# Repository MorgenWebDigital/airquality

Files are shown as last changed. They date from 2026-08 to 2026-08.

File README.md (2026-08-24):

# AirQuality

A battery-powered indoor air quality monitor. Real CO₂ from a photoacoustic
sensor, VOC and NOx, temperature, humidity and ambient light, shown on a 2.13"
e-paper display and sent over Bluetooth LE.

Two layers, 45 × 95 mm, 76 electrical components, one 21700 lithium cell.

| front | back |
|---|---|
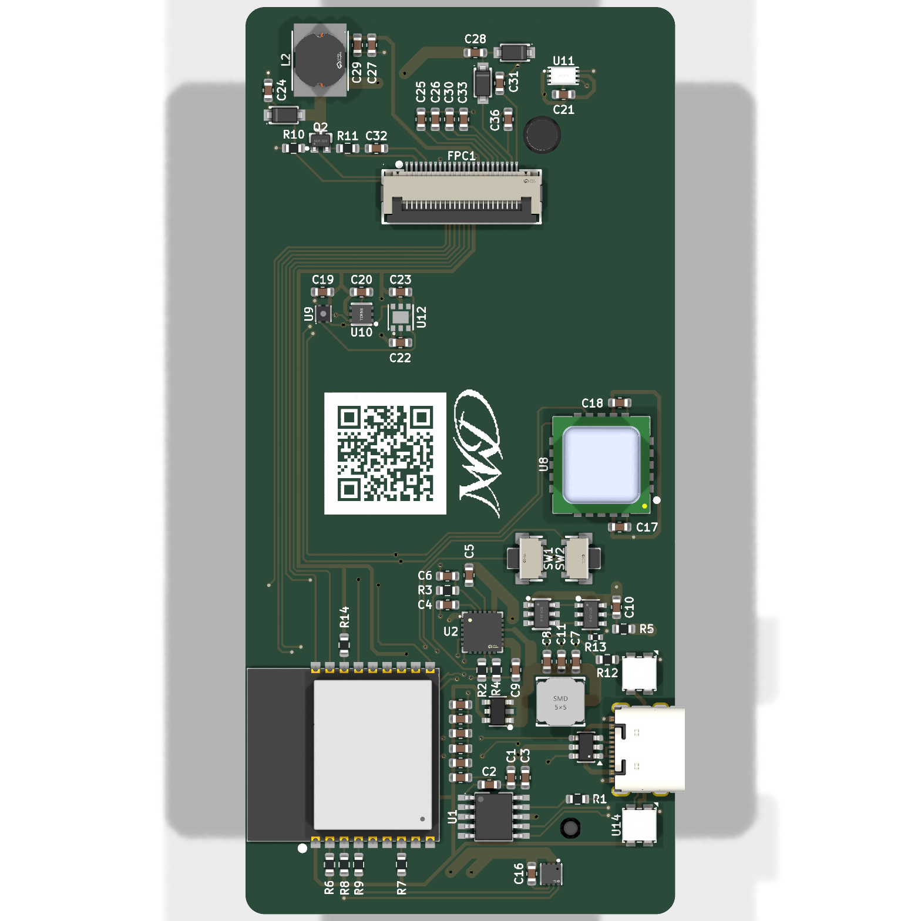
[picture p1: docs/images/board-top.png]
front
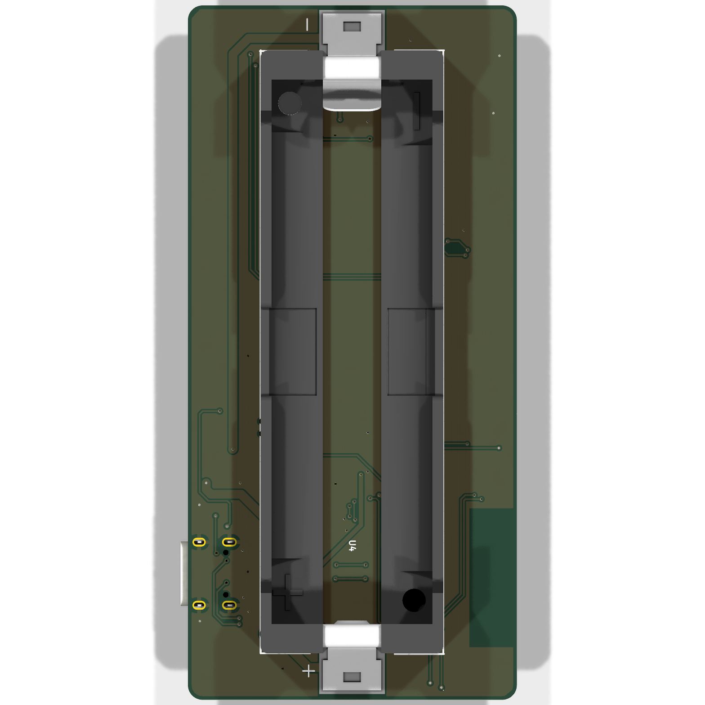
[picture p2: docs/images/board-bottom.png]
back
|  |  |

---

## 1. What it measures

| Sensor | Measures | Accuracy | I²C |
|---|---|---|---|
| **SCD40** | CO₂, photoacoustic, a real measurement rather than an estimate | ±(50 ppm + 5 % of reading) | `0x62` |
| **SGP41** | VOC and NOx index | index, not a concentration | `0x59` |
| **SHT41** | humidity and temperature | ±1.8 %RH, ±0.2 °C | `0x44` |
| **T117Z** | temperature, the precision channel | ±0.1 °C, 16 bit | `0x48` |
| **BH1750** | ambient light | 1 lx resolution, 1–65535 lx | `0x23` |
| **MAX17048** | state of charge of the cell | ±1 %, no shunt needed | `0x36` |
| **BQ25895** | charger status and control | - | `0x6A` |

Everything shares one I²C bus. The addresses do not collide.

The SCD40 is the only sensor that measures CO₂ directly. The SGP41 reports a
VOC and a NOx index derived from a heated metal-oxide cell. That reads as "the
air is getting stale", and is not comparable to a ppm figure.

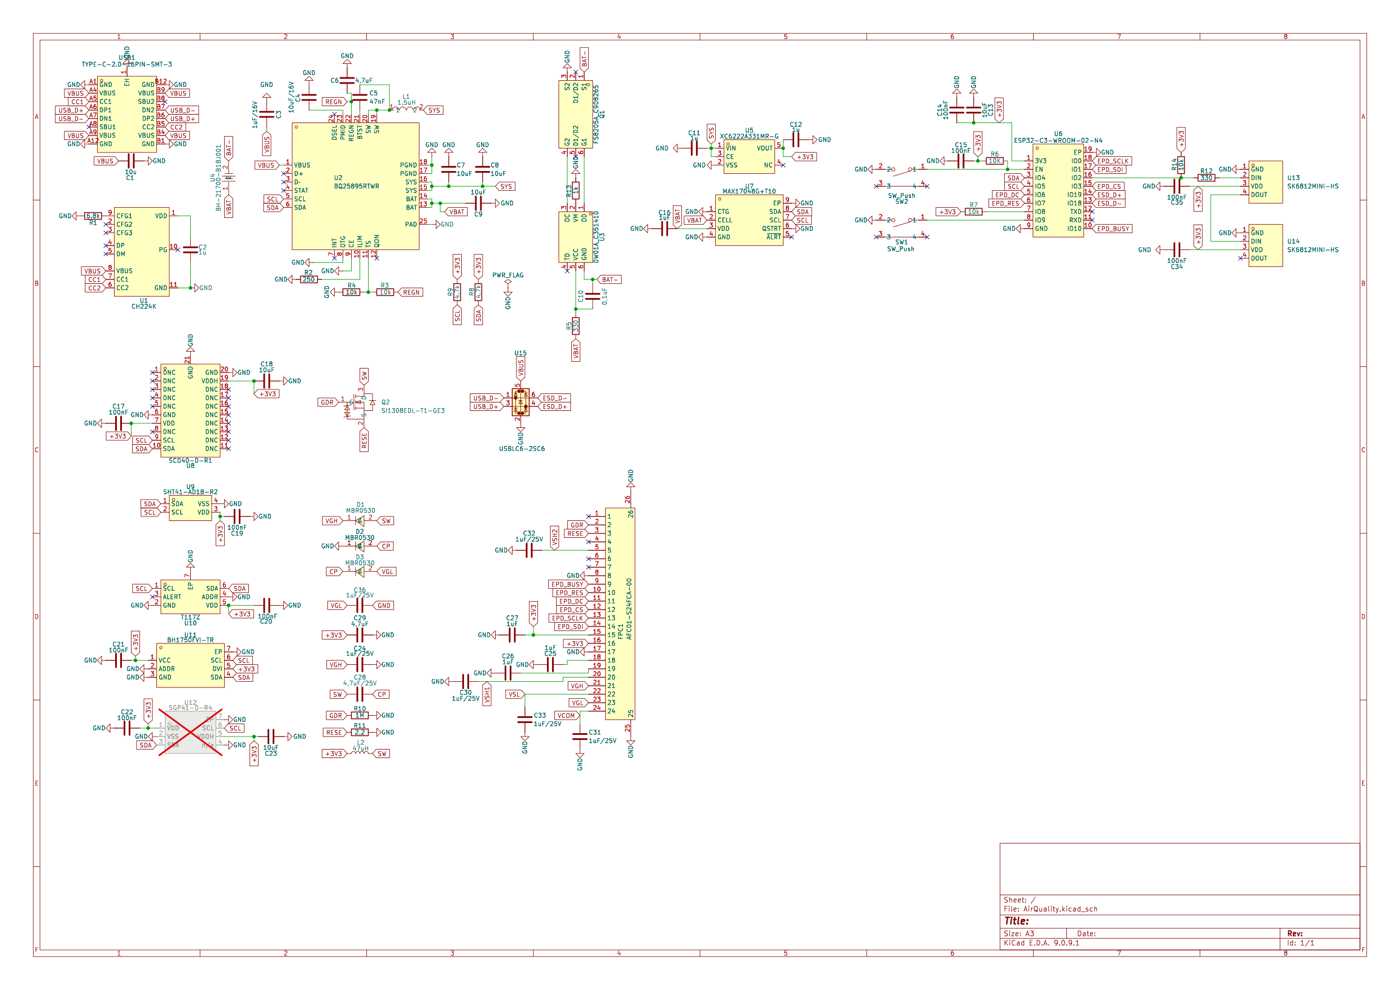
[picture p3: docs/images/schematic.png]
schematic


The full schematic as a PDF is in [`docs/schematic.pdf`](docs/schematic.pdf).

---

## 2. How the power works

```text
   USB-C ──▶ CH224K ──▶ VBUS ──▶ BQ25895 ──▶ SYS ──▶ XC6222 ──▶ 3.3 V
             requests            charger            LDO         MCU, sensors,
             9 V over PD                                        display
                                    │
                                    ▼
                                  21700 cell
                                    │
                              DW01A + FS8205A
                              cell protection
```

The **CH224K** negotiates 9 V over USB Power Delivery. At 9 V the charger draws
about half the current it would at 5 V for the same charging power. Less loss
in the cable, less heat. A 6.8 kΩ resistor on CFG1 selects the voltage; the
value comes straight from the table in the CH224K datasheet.

The **BQ25895** is a switching charger, not a linear one. It can deliver up to
5 A; the input current limit is set by a 250 Ω resistor to about 2.1 A. It also
provides the power path, so the device runs from USB while charging.

The cell is a **Molicel INR21700-P45B**, which ships unprotected. **DW01A** with
an **FS8205A** dual MOSFET adds over-charge, over-discharge and over-current
protection. A 1 kΩ resistor sits between the DW01A's VM pin and the pack
negative, as the datasheet's application circuit requires. Without it, plugging
in a charger while the protection has tripped puts the full charger voltage on
that pin with nothing to limit the current.

The **XC6222** drops SYS to 3.3 V. Its CE pin is tied to SYS: the regulator is
always on while the cell has charge. It cannot be switched off from the ESP32,
because the ESP32 hangs on that same rail and could never switch it back on.

---

## 3. The display

A 2.13" e-paper panel (GDEY0213B74, SSD1680 controller) on a 24-pin 0.5 mm FPC
connector. Bistable: it holds the image with no power at all, and only draws
current while updating.

The panel needs gate and source rails well beyond 3.3 V. They are generated on
the board, following the reference circuit in the panel's datasheet:

- a boost converter produces **VGH**: a 47 µH inductor and an SI1308 MOSFET,
  driven by the panel's own GDR output with a 2.2 Ω sense resistor on RESE
- a charge pump off the same switching node produces the negative **VGL**
- the other rails (VSH1, VSH2, VSL, VCOM) come from the panel's internal
  regulators and only need decoupling

All seven capacitors on these rails are rated **25 V**. That is not decoration:
VGH runs above 20 V, and a standard 1 µF 0603 from the shelf is often a 6.3 or
16 V part.

**BS1 is tied low**, which selects 4-wire SPI, matching the SDA/SCL/CS/DC/RES
wiring used here.

**Update budget.** The panel is rated for one million updates *or* five years,
whichever comes first. At one update per minute the update budget is gone in
under two years; at three minutes and longer, the five-year limit is reached
first. Redrawing no more often than every three minutes, and only when a value
actually changes, keeps the panel inside both limits.

---

## 4. Board details

| | |
|---|---|
| Size | 45 × 95 mm |
| Layers | 2, 35 µm copper |
| Ground | pour on the back, 3306 mm² |
| Minimum clearance | 0.2 mm |
| Minimum track | 0.2 mm |
| Vias | 0.6 mm pad, 0.3 mm drill |

**The ESP32 antenna** sits at the board edge with a keep-out on both copper
layers. Nothing is routed through it: no track, no via, no pour.

**ESD protection** on the USB data lines: a USBLC6-2SC6 sits 1.9 mm from the
connector pads, with the signal routed *through* the device rather than
branched off it, and a ground via right at its ground pad. Both matter more
than they look: an ESD pulse rises in under a nanosecond, and every millimetre
of track between the connector and the clamp adds roughly 35 V of overshoot
that the ESP32 then sees.

**U12 (SGP41) is marked do-not-populate.** The footprint and routing are there;
the part is left off in the current build. Fitting it later needs no board
change.

---

## 5. Building one

Everything needed is in this repository.

**Boards.** [`production/AirQuality-gerber.zip`](production/) goes straight to a
fab house. Two layers, 1.6 mm, 35 µm copper, any standard process. The zip holds
the Gerbers and the Excellon drill files.

**Parts.** [`production/AirQuality-bom.csv`](production/) lists every component
with its LCSC number where one exists.
[`production/AirQuality-positions.csv`](production/) is the pick-and-place file.

**Datasheets** for every active part are in [`datasheets/`](datasheets/), named
by LCSC part number.

**Opening the design.** KiCad 9. Open
[`hardware/AirQuality.kicad_pro`](hardware/). All symbols, footprints and 3D
models live in `hardware/libraries/` and are referenced relatively, so the
project opens from any location.

**Mechanical.** [`docs/AirQuality.step`](docs/) is the full board with all
components, for enclosure design.

---

## 6. Design notes

Longer notes on why things are the way they are:

- [`docs/design-notes.md`](docs/design-notes.md): component choices and the
  reasoning behind them
- [`docs/track-widths.md`](docs/track-widths.md): current, trace widths and
  the IPC-2221 arithmetic

---

## 7. Verification

The board passes with no electrical findings:

```text
   ERC                      0 errors, 0 warnings
   Unconnected pads         0
   Shorts                   0
   Clearance violations     0
   Schematic parity         0
```

Every integrated circuit has been checked pin by pin against its datasheet. Not
against memory or a symbol's label, but against the document in
[`datasheets/`](datasheets/).

Remaining DRC output is silkscreen only: reference designators over copper and
part outlines crossing the board edge at the connectors. Neither affects
manufacture.

---

## 8. License

[PolyForm Noncommercial 1.0.0](LICENSE). Any use is permitted except a
commercial one.

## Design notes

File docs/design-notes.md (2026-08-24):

# Design notes

Why the parts are what they are, and what was tried before them. Written from
the board as built, not from the plan. The two diverged along the way.

---

## 1. Sensors

**SCD40 for CO₂.** The only sensor here that measures CO₂ rather than guessing
at it. It works photoacoustically: infrared light is pulsed at CO₂ molecules in
a small chamber, they warm and expand, and a microphone hears the pressure
pulse. Accuracy ±(50 ppm + 5 % of reading).

Its datasheet is unusually specific about the supply: ripple below 30 mV
peak-to-peak, no large transient drops, and a low-dropout regulator preferred.
That is not politeness. The sensor draws 205 mA peaks during a measurement and
18 mA average, and a supply that sags under that peak gives wrong readings.
VDD and VDDH must sit at the same voltage and are tied together close to the
part.

**SGP41 for VOC and NOx.** A heated metal-oxide cell. It reports an *index*,
not a concentration. It reads as "the air is getting stale", and is not
comparable to ppm. It is the only part on the board that heats continuously
while measuring, at about 11 mW.

The plan originally called for an ENS160. It needs a 1.71–1.98 V core supply,
which would have meant a second regulator on a board that otherwise runs on one
rail. The SGP41 runs from 3.3 V and needed no extra hardware.

**SHT41 and T117Z for temperature.** Two sensors on purpose. The SHT41 gives
humidity plus a temperature good to ±0.2 °C. The T117Z is a
TMP117-register-compatible part from Mysentech that reaches ±0.1 °C for a
fraction of the TI original's price. It is the precision channel; the SHT41's
temperature is there mostly to compensate its own humidity reading.

The T117Z's ADD0 pin is tied to ground, which selects address `0x48`.

**BH1750 for light.** Its DVI pin is the I²C reference voltage, not a reset.
Tied to 3.3 V it sets the logic level. ADDR to ground gives `0x23`.

---

## 2. Power

**Why a PD trigger at all.** The CH224K negotiates 9 V over USB Power Delivery
instead of accepting the default 5 V. For the same charging power the input
current halves: less loss in the cable, less heat in the connector, less heat
in the charger. A 6.8 kΩ resistor on CFG1 selects 9 V; the value is the
datasheet's, not a guess. CFG2 and CFG3 must be left floating for the
single-resistor mode, and they are.

9 V is also comfortably inside the BQ25895's 3.9–14 V input range.

**Why a switching charger.** The plan started with an MCP73831, a linear
charger limited to 0.5 A. A 4500 mAh cell at 0.5 A takes nine hours, and the
regulator burns the difference between input and cell voltage as heat. The
BQ25895 switches instead, handles up to 5 A, and can be told what to do over
I²C. The input current limit is set by a 250 Ω resistor to about 2.1 A.

The TS pin has a fixed 10 k/10 k divider from REGN instead of a thermistor,
which puts it at 50 % of REGN, inside the window where the charger considers
the cell temperature normal and charges. Adding a real NTC later needs only the
two resistors swapped.

**Why cell protection is separate.** The Molicel P45B ships unprotected. The
DW01A watches the cell and switches an FS8205A dual MOSFET: over-charge above
4.25 V, over-discharge below 2.4 V, over-current, short circuit. It works
whether or not the charger is running or the microcontroller is awake.

The FS8205A's two drains are internally connected and brought out on pins 2 and
5; both are left unconnected, which is correct. The pair sits in series in the
cell's negative path with the sources at either end.

A 1 kΩ resistor sits between the DW01A's VM pin and the pack negative. The
datasheet's application circuit shows it and the reason is in the absolute
maximum ratings: VM tolerates VDD−24 V to VDD+0.3 V. With the protection
tripped and a charger connected, the full charger voltage lands on that pin,
and without the resistor nothing limits the current into it. Leaving it out is
a known way to kill a DW01A.

**Why the regulator can't be switched off.** The XC6222's CE pin is active
high and tied to SYS, so the regulator runs whenever the cell has charge. It is
tempting to put that pin on a GPIO for a hard power-down, but the ESP32 runs
from the very rail it would be switching, and could never switch it back on.

---

## 3. The e-paper supply

The panel's own controller runs the boost converter: it drives the gate of an
external MOSFET from its GDR pin and senses the current on RESE. All the board
provides is the power stage: a 47 µH inductor, an SI1308 MOSFET, a 2.2 Ω sense
resistor and three Schottky diodes.

Two things about this circuit are easy to get wrong, and both were:

**Diode polarity.** For the boost, the anode must sit at the switching node.
Otherwise the inductor has nowhere to dump its energy when the MOSFET turns
off, VGH never rises, and the MOSFET sees uncontrolled flyback. The same logic
inverts for the charge pump that makes the negative VGL. All three diodes were
built the wrong way round at first. The trap is the symbol: for the MBR0530
used here, **pin 1 is the cathode**, not the anode.

**Capacitor voltage rating.** VGH runs above 20 V and VGL to about −20 V. A
1 µF 0603 from the shelf is frequently rated 6.3 or 16 V. The reference circuit
specifies 25 V for all of them, and the bill of materials now says so
explicitly.

A 25 V X5R at 20 V bias also loses 60–80 % of its nominal capacitance to DC
bias. The panel manufacturer evidently accounts for that; if in doubt, a 50 V
part or an 0805 case gives back the margin.

---

## 4. Layout decisions

**The antenna.** The ESP32 module sits with its antenna at the board edge, and
a keep-out covers that area on both copper layers: no pour, no track, no via.
A ground plane under a module antenna detunes it badly enough to make the radio
useless.

**ESD at the connector.** The USB data lines pass *through* a USBLC6-2SC6, in
on one pin of a channel and out on the other, rather than having the protection
hang off them as a stub. The device sits 1.9 mm from the connector pads, with a
ground via directly at its ground pad.

Both details come from the same arithmetic. An IEC 61000-4-2 pulse at 8 kV has
a first peak near 30 A with a rise time around 0.8 ns. A track over a ground
plane has roughly 1 nH per millimetre. That gives **about 35 V of overshoot per
millimetre** of track between the connector and the clamp. The ground return
counts in the same loop, which is why the via matters as much as the
distance.

**Current and track width.** See [`track-widths.md`](track-widths.md).

---

## 5. What is deliberately not fitted

**U12, the SGP41, is marked do-not-populate** in the current build. Its
footprint, routing and I²C address are all present; fitting it later needs no
board change, only the part. It does not appear in the bill of materials or the
pick-and-place file, which is the point of the marking.

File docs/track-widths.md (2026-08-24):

# Track widths and current

Copper is 35 µm (1 oz), all tracks on outer layers. Widths follow
**IPC-2221** at a 10 K temperature rise, which is the conservative end of that
standard.

---

## 1. The arithmetic

IPC-2221 gives the cross-section for a permitted temperature rise:

```text
   I = k · ΔT^0.44 · A^0.725        k = 0.048 for outer layers
```

Solved for width at 35 µm copper and ΔT = 10 K:

| Current | Width needed |
|---|---|
| 0.5 A | 0.12 mm |
| 1.0 A | 0.30 mm |
| 2.0 A | 0.78 mm |
| 2.25 A | 0.92 mm |
| 3.0 A | 1.37 mm |
| 4.5 A | 2.39 mm |

Doubling the permitted rise to 20 K cuts these by roughly a third, but 10 K
leaves room for a warm enclosure and for the charger running beside them.

---

## 2. What actually flows

The cell is a Molicel INR21700-P45B, 4500 mAh. Charge rates:

- **0.5 C = 2.25 A**, the intended default. Cooler, gentler on the cell.
- **1 C = 4.5 A** is possible; the BQ25895 handles up to 5 A and can be told to
  over I²C.

On the input side the CH224K requests 9 V, so the same charging power needs
about half the current a 5 V supply would. The input limit is set by a 250 Ω
resistor to roughly 2.1 A.

On the 3.3 V rail the worst case is the ESP32 transmitting (345 mA) while the
SCD40 measures (205 mA), around 560 mA, and only in bursts of milliseconds.

---

## 3. What is on the board

| Net | Carries | Width on the board |
|---|---|---|
| **BAT−** | full cell current, up to 4.5 A | 0.80 – 1.20 mm |
| **VBAT** | full cell current | 0.50 – 1.20 mm |
| **SYS** | system rail from the charger | 0.20 – 1.20 mm |
| **SW** | the charger's switching node | 1.20 mm |
| **VBUS** | input from USB, up to ~2.1 A at 9 V | 0.20 – 0.60 mm |
| **+3V3** | up to ~560 mA in bursts | 0.20 – 0.40 mm |
| **GND** | return, backed by the pour | 0.20 – 0.50 mm |
| VGH, VGL | display gate rails, microamps | 0.20 mm |
| signals | I²C, SPI, USB, buttons | 0.20 mm |

The minima are narrow because a track does not carry its full current over its
whole length. Where a wide track has to reach a pad on a 0.5 mm pitch package,
or squeeze between a via and a pad, it narrows for a millimetre or two and
widens again. The heating over such a short stretch is spread by the copper on
either side.

The **switching node SW is kept at a constant 1.2 mm** and as short as the
placement allows. It is not a current question. It is the node with the
steepest edges on the board, and its loop area sets how much of that ends up
as radiated noise.

**Ground returns through the pour**, not through tracks. The 0.2 mm ground
segments are stubs from pads to vias, not current paths.

---

## 4. The limit that actually bit

Widening tracks is not free. On a dense board the widened copper runs out of
clearance to its neighbours, and the design rule here is 0.2 mm.

Several places needed a compromise: the track was widened over its free run and
kept narrow where it passes a pad or a via. Two spots were caught at under
0.1 mm during review, one of them **VBAT against ground near the cell**. At
that spacing an etching defect bridges the two, which on a lithium cell is not
a cosmetic problem.

The rule of thumb that came out of it: widen the free stretches, leave the
pinch points alone, and let the DRC decide where the boundary is.

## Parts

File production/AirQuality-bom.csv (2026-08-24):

Reference | Value | Footprint | Quantity | LCSC | Datasheet
C1 | 10u | Capacitor_SMD:C_0603_1608Metric | 1 |  | ~
C2,C11,C12 | 1u | Capacitor_SMD:C_0603_1608Metric | 3 |  | ~
C3 | 1uF/16V | Capacitor_SMD:C_0603_1608Metric | 1 |  | ~
C4 | 10uF/16V | Capacitor_SMD:C_0603_1608Metric | 1 |  | ~
C5 | 47nF | Capacitor_SMD:C_0603_1608Metric | 1 |  | ~
C6,C29 | 4,7uF | Capacitor_SMD:C_0603_1608Metric | 2 |  | ~
C7-C9,C13,C18,C23 | 10uF | Capacitor_SMD:C_0603_1608Metric | 6 |  | ~
C10 | 0,1uF | Capacitor_SMD:C_0603_1608Metric | 1 |  | ~
C14,C15,C17,C19-C22,C34,C35 | 100nF | Capacitor_SMD:C_0603_1608Metric | 9 |  | ~
C16,C25-C27 | 1uF | Capacitor_SMD:C_0603_1608Metric | 4 |  | ~
C24,C30-C33,C36 | 1uF/25V | Capacitor_SMD:C_0603_1608Metric | 6 |  | ~
C28 | 4,7uF/25V | Capacitor_SMD:C_0603_1608Metric | 1 |  | ~
D1-D3 | MBR0530 | AirQuality:SOD-123_L2.8-W1.8-LS3.7-RD | 3 | C77336 | https://lcsc.com/product-detail/Schottky-Barrier-Diodes-SBD_MBR0530_C77336.html
FPC1 | AFC01-S24FCA-00 | AirQuality:FPC-SMD_24P-P0.50_AFC01-S24FCA-00 | 1 | C262669 | https://lcsc.com/product-detail/FPC-Connectors_JUSHUO-AFC01-S24FCA-00_C262669.html
L1 | 1.5uH | AirQuality:IND-SMD_L5.0-W5.0_SWPA5040S | 1 | C96922 | https://lcsc.com/product-detail/Power-Inductors_1-5uH-30_C96922.html
L2 | 47uH | AirQuality:IND-SMD_L5.8-W5.2 | 1 |  | ~
Q1 | FS8205A_C908265 | AirQuality:SOT-23-6_L2.9-W1.6-P0.95-LS2.8-BR | 1 | C908265 | https://lcsc.com/product-detail/MOSFET_FUXINSEMI-FS8205A_C908265.html
Q2 | SI1308EDL-T1-GE3 | AirQuality:SOT-323_L2.0-W1.3-P1.30-LS2.1-BR | 1 | C469327 | https://www.lcsc.com/datasheet/C469327.pdf
R1 | 6.8k | Resistor_SMD:R_0603_1608Metric | 1 |  | ~
R2 | 250 | Resistor_SMD:R_0603_1608Metric | 1 |  | ~
R3,R4,R7,R14 | 10k | Resistor_SMD:R_0603_1608Metric | 4 |  | ~
R5,R12 | 330 | Resistor_SMD:R_0603_1608Metric | 2 |  | ~
R6 | 10K | Resistor_SMD:R_0603_1608Metric | 1 |  | ~
R8,R9 | 4.7k | Resistor_SMD:R_0603_1608Metric | 2 |  | ~
R10 | 1M | Resistor_SMD:R_0603_1608Metric | 1 |  | ~
R11 | 2,2 | Resistor_SMD:R_0603_1608Metric | 1 |  | ~
R13 | 1k | Resistor_SMD:R_0402_1005Metric | 1 |  | ~
SW1,SW2 | SW_Push | AirQuality:SW-SMD_2P-TS24CA | 2 | C393942 | https://lcsc.com/product-detail/Tactile-Switches_SHOU-HAN-TS24CA_C393942.html
U1 | CH224K | AirQuality:ESSOP-10_L4.9-W3.9-P1.0-LS6.0-TL-EP | 1 | C970725 | https://www.lcsc.com/datasheet/C970725.pdf
U2 | BQ25895RTWR | AirQuality:QFN-24_L4.0-W4.0-P0.50-TL-EP2.7 | 1 | C80200 | https://lcsc.com/product-detail/PMIC-Battery-Management_TI_BQ25895RTWR_BQ25895RTWR_C80200.html
U3 | DW01A_C351410 | AirQuality:SOT-23-6_L2.9-W1.6-P0.95-LS2.8-BL | 1 | C351410 | https://lcsc.com/product-detail/Others_PUOLOP-DW01_C351410.html
U4 | BH-21700-B1BJ001 | AirQuality:BAT-SMD_L82.5.5-W25-BH-21700-B1BJ001 | 1 | C20606791 | https://www.lcsc.com/datasheet/C20606791.pdf
U5 | XC6222A331MR-G | AirQuality:SOT-25-5_L2.9-W1.6-P0.95-LS2.8-BR | 1 | C5375082 | https://www.lcsc.com/datasheet/C5375082.pdf
U6 | ESP32-C3-WROOM-02-N4 | AirQuality:BULETM-SMD_ESPRESSIF_ESP32-C3-WROOM-02-N4-4MB | 1 | C2934560 | https://www.lcsc.com/datasheet/C2934560.pdf
U7 | MAX17048G+T10 | AirQuality:TDFN-8_L2.0-W2.0-P0.50-BL-EP1.2 | 1 | C2682616 | https://www.lcsc.com/datasheet/C2682616.pdf
U8 | SCD40-D-R1 | AirQuality:LGA-20_L10.1-W10.1-P1.25-TL | 1 | C3037696 | https://www.lcsc.com/datasheet/C3037696.pdf
U9 | SHT41-AD1B-R2 | AirQuality:DFN-4_L1.5-W1.5-SHT41-AD1B-R2 | 1 | C7461861 | https://www.lcsc.com/datasheet/C7461861.pdf
U10 | T117Z | AirQuality:TDFN-6_L2.0-W2.0-P0.65-TL-EP | 1 | C19284876 | https://www.lcsc.com/datasheet/C19284876.pdf
U11 | BH1750FVI-TR | AirQuality:WSOF-6_L2.6-W1.6-P0.50-TL-EP | 1 | C78960 | https://lcsc.com/product-detail/Sensors_ROHM_BH1750FVI-TR_BH1750FVI-TR_C78960.html
U12 | SGP41-D-R4 | AirQuality:DFN-6_L2.4-W2.4-P0.80-TL-EP | 1 | C3659325 | https://www.lcsc.com/datasheet/C3659325.pdf
U13,U14 | SK6812MINI-HS | AirQuality:LED-SMD_4P-L3.5-W3.5-BR_SK6812MINI-HS | 2 | C2922787 | https://www.lcsc.com/datasheet/C2922787.pdf
U15 | USBLC6-2SC6 | Package_TO_SOT_SMD:SOT-23-6 | 1 |  | https://www.st.com/resource/en/datasheet/usblc6-2.pdf
USB1 | TYPE-C-2.0-16PIN-SMT-3 | AirQuality:TYPE-C-SMD_TYPE-CF3.1 | 1 | C2987386 | https://www.lcsc.com/datasheet/C2987386.pdf

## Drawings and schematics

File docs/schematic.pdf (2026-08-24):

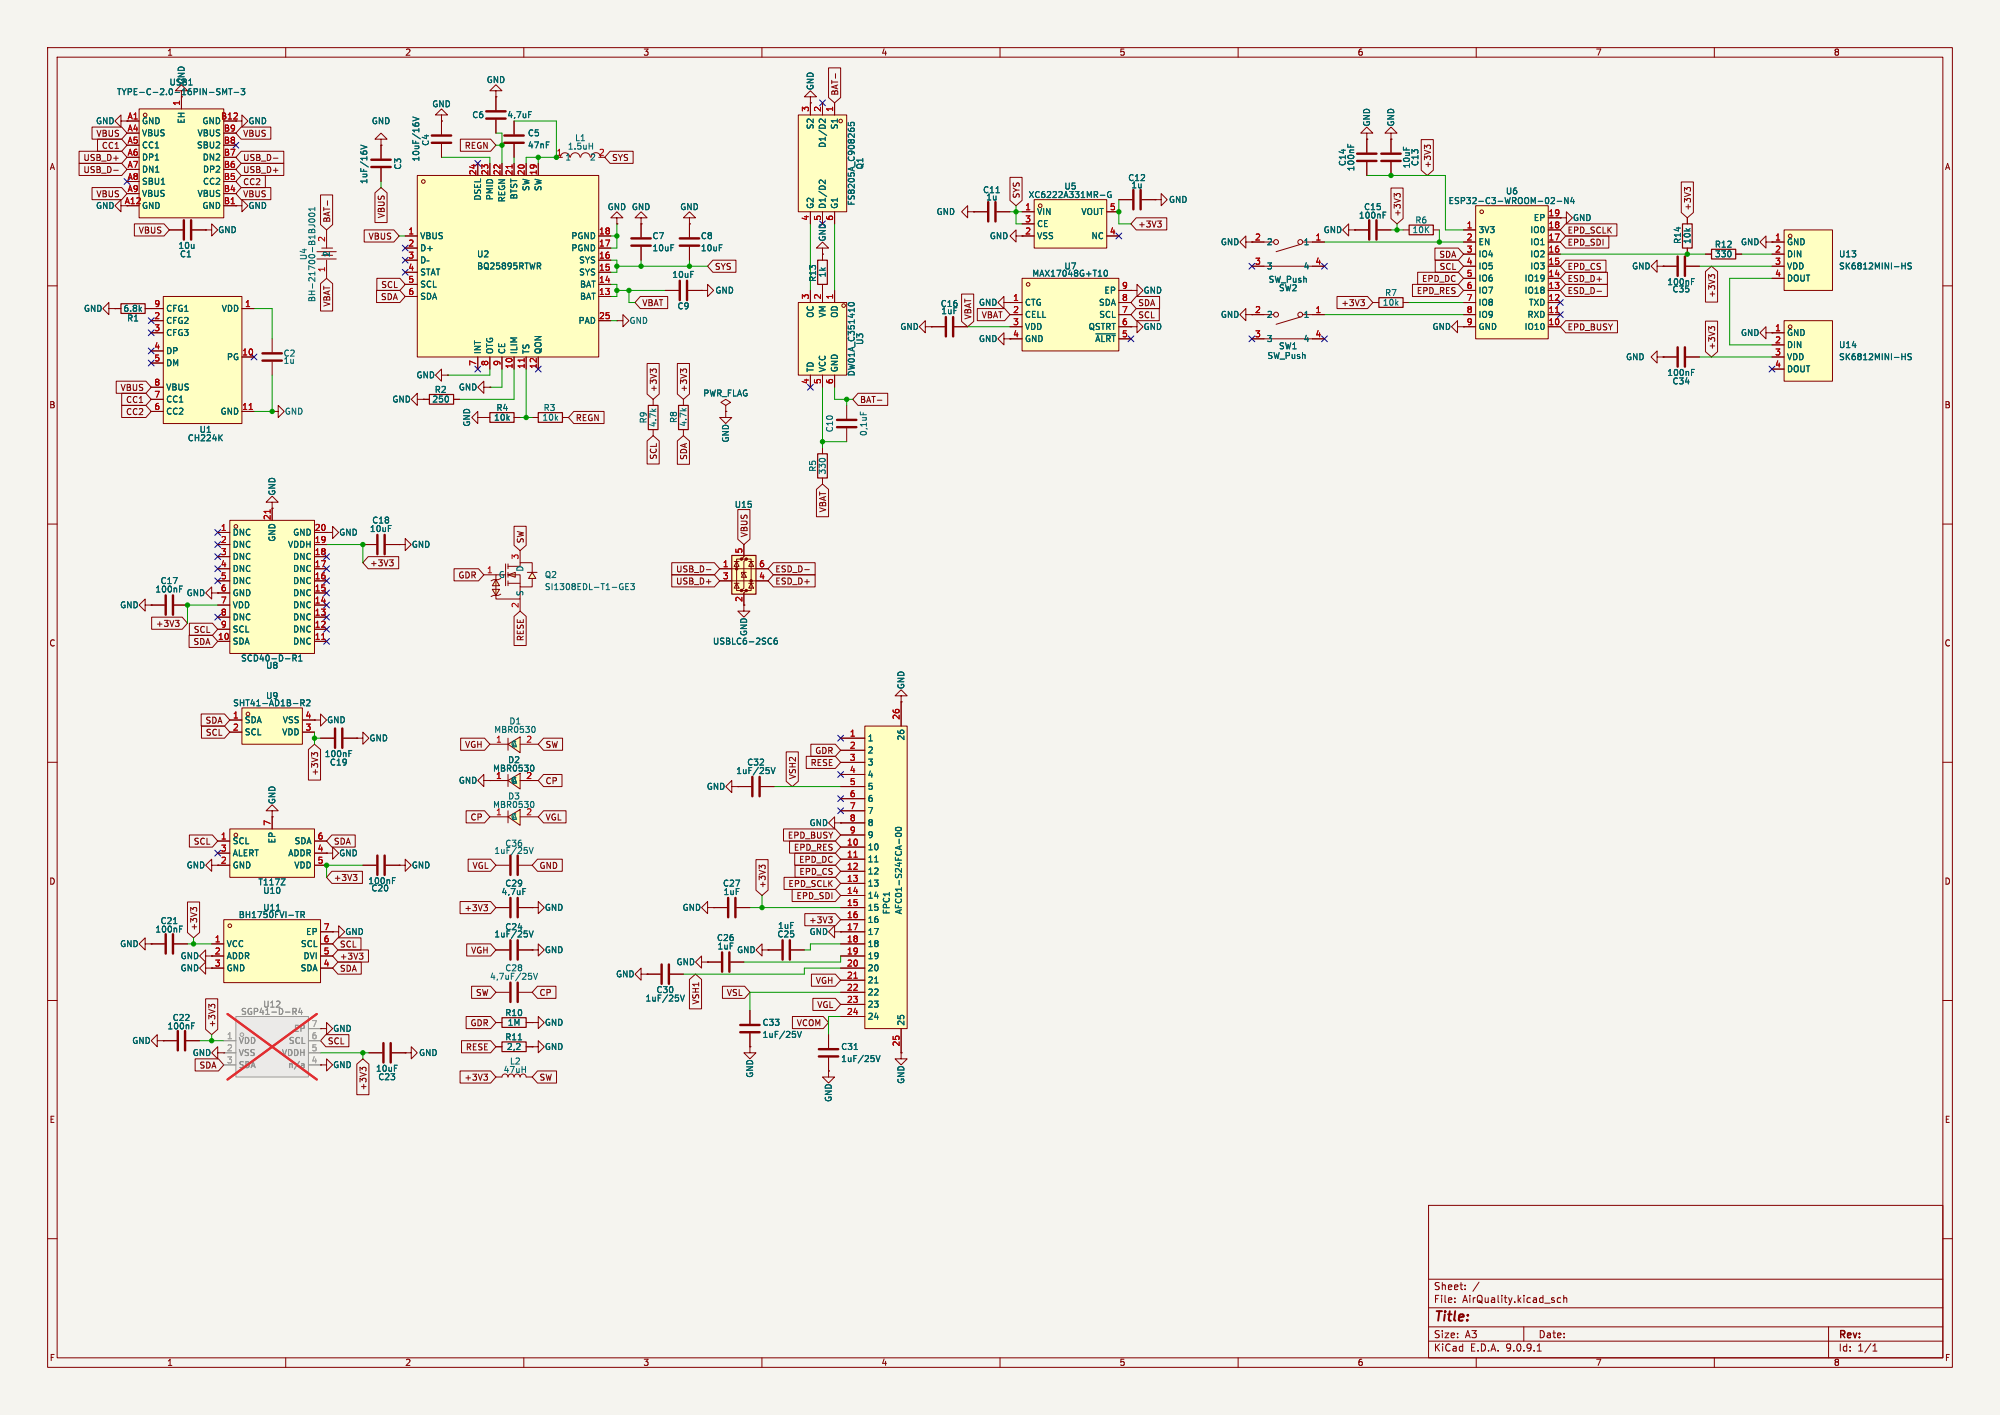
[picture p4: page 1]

1 GNDB12 VBUS B9 SBU2 B8 DN2 B7 DP2 B6 CC2 B5 VBUS B4 GND B1 USB1 TYPE-C-2.0-16PIN-SMT-3

2 U4 BH-21700-B1BJ001 GND C3 1uF/16V C4 10uF/16V GND GND GND

9 BTST 21 ILIM 10 SW 20 TS 11 SW 19 QON 12 PGND 18 PGND 17 SYS 16 SYS 15 BAT 14 BAT 13 PAD 25 U2BQ25895RTWR

9 BTST 21 ILIM 10 SW 20 TS 11 SW 19 QON 12 PGND 18 PGND 17 SYS 16 SYS 15 BAT 14 BAT 13 PAD 25 R4

7 SDA 6 ADDR 4 VDD 5 U10 T117Z GND

7 SDA 6 ADDR 4 VDD 5 GND

Id: 1/1 Title: File: AirQuality.kicad_sch Sheet: /

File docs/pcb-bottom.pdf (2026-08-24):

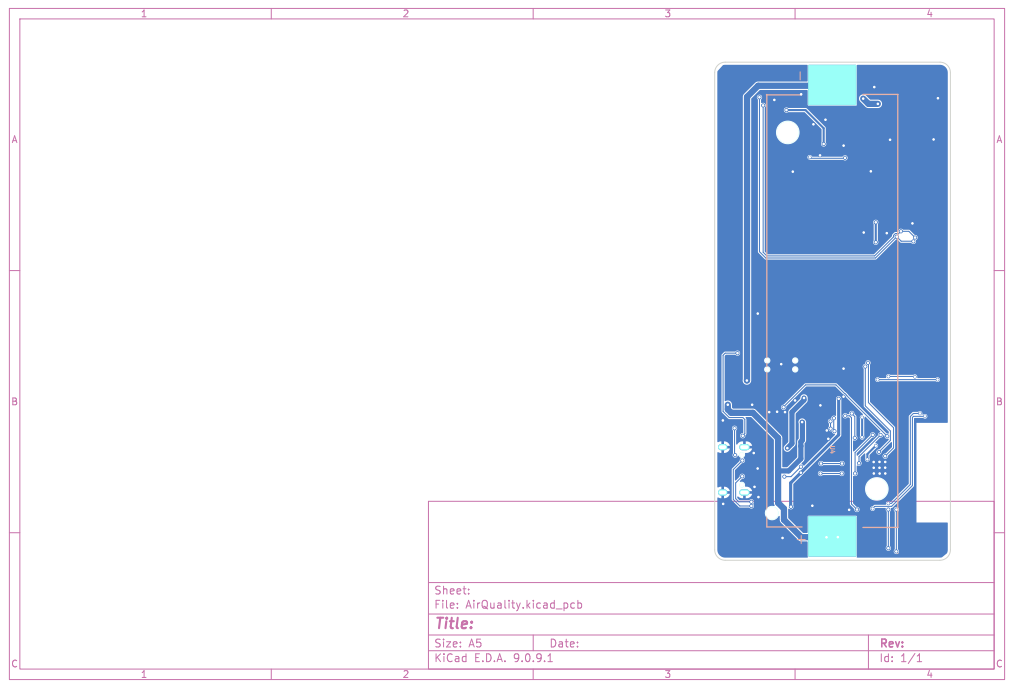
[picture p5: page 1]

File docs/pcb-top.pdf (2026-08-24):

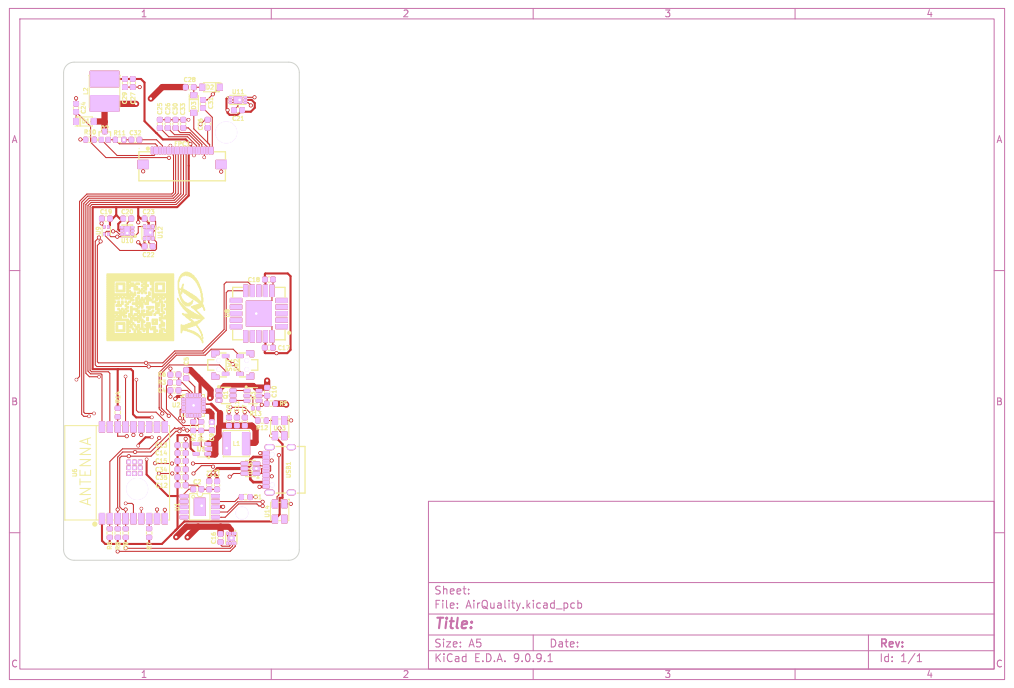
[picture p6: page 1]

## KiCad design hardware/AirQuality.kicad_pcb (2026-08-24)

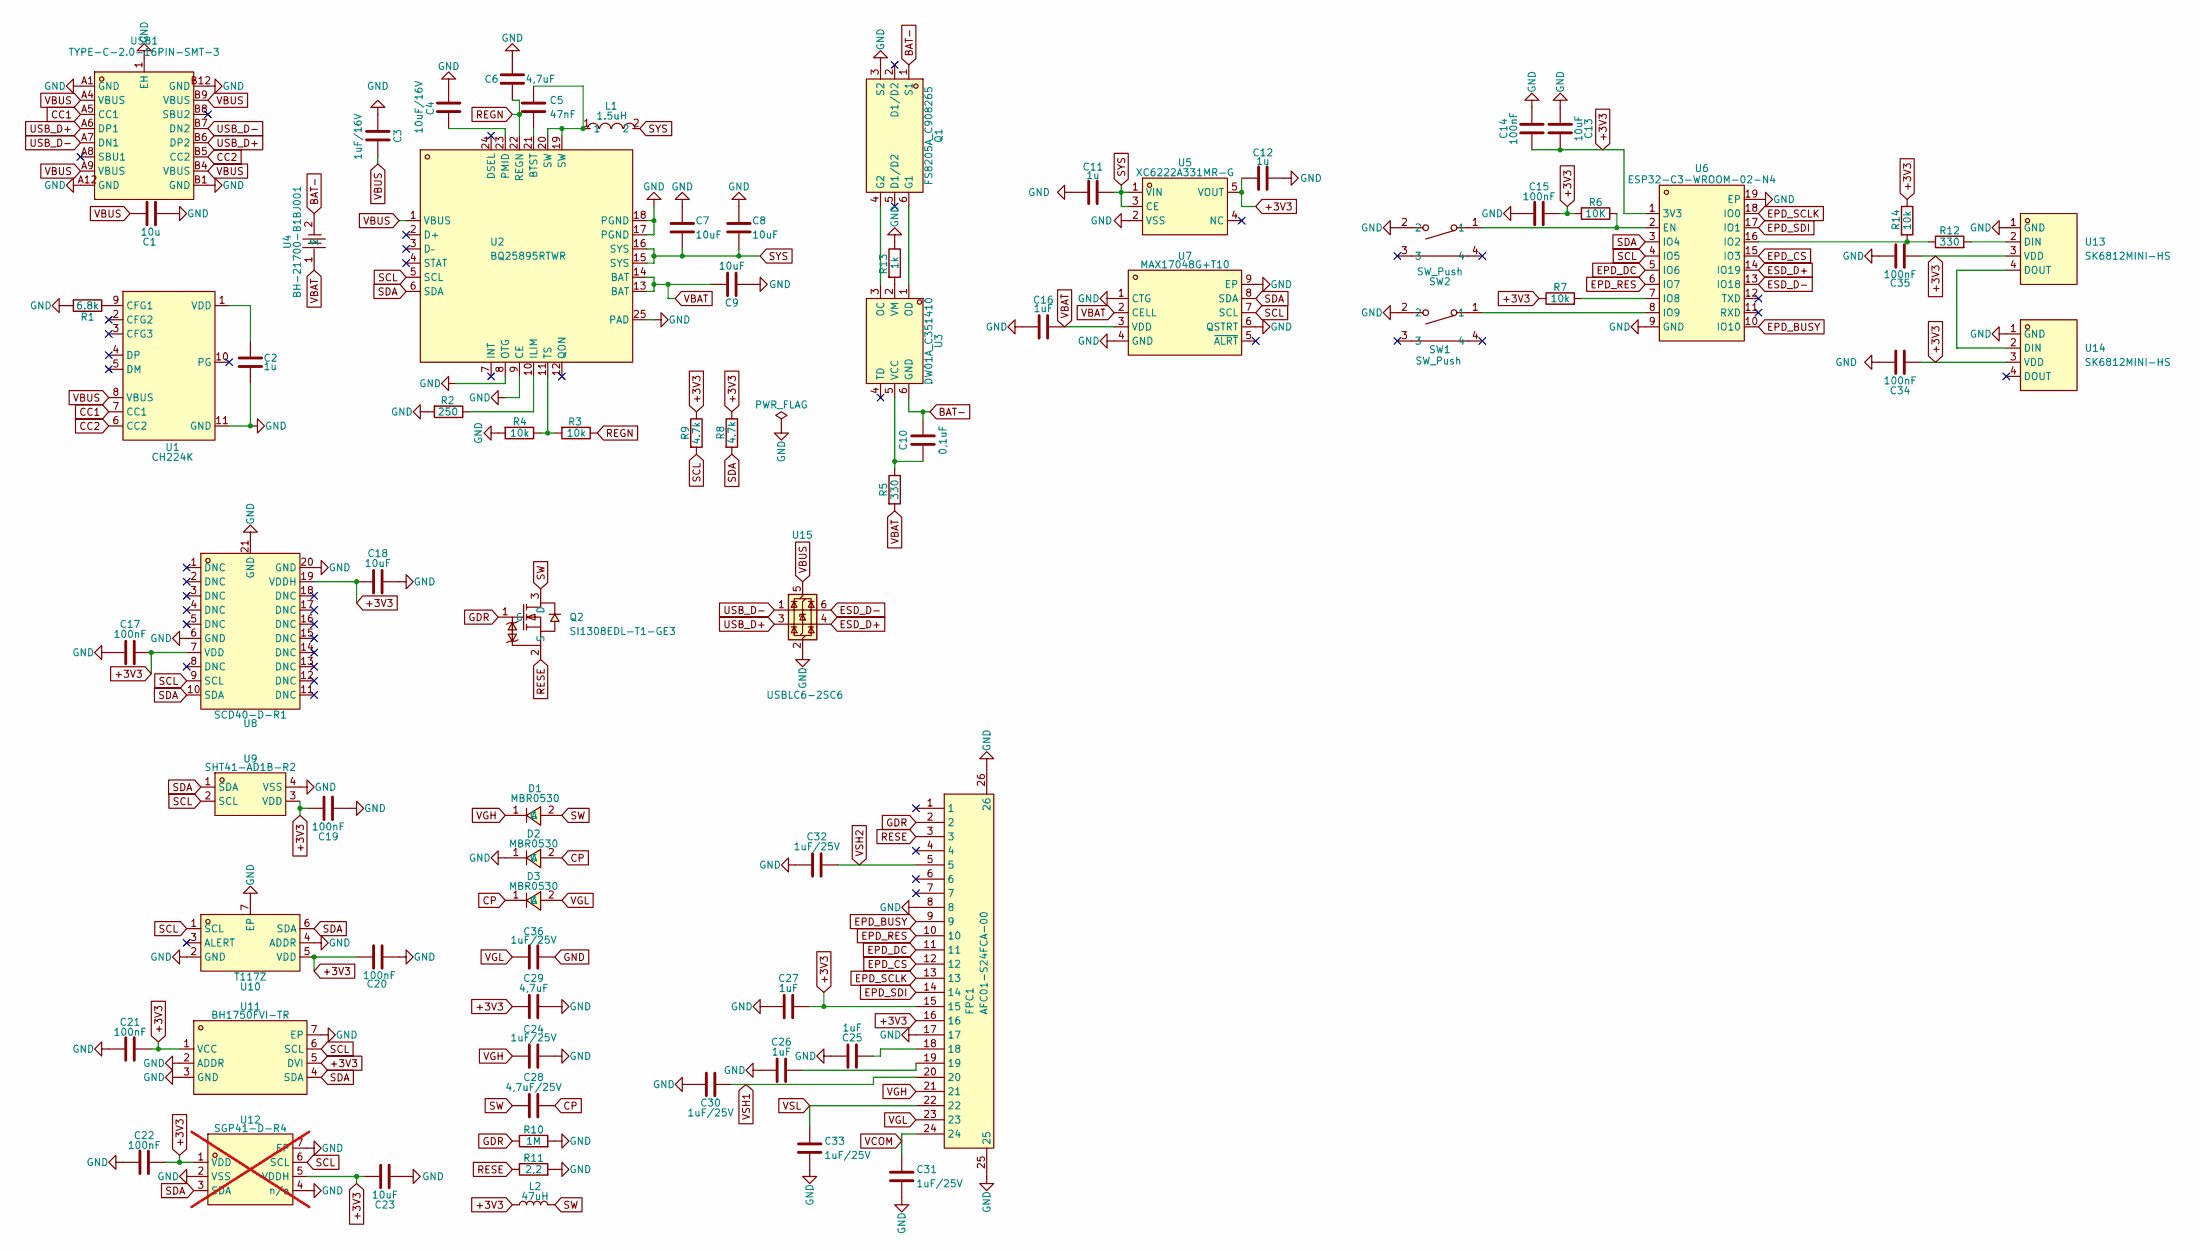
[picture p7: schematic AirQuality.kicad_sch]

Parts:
C1: 10u; C_0603_1608Metric
C2, C11, C12: 1u; C_0603_1608Metric
C3: 1uF/16V; C_0603_1608Metric
C4: 10uF/16V; C_0603_1608Metric
C5: 47nF; C_0603_1608Metric
C6, C29: 4,7uF; C_0603_1608Metric
C7, C8, C9, C13, C18, C23: 10uF; C_0603_1608Metric
C10: 0,1uF; C_0603_1608Metric
C14, C15, C17, C19, C20, C21, C22, C34, C35: 100nF; C_0603_1608Metric
C16, C25, C26, C27: 1uF; C_0603_1608Metric
C24, C30, C31, C32, C33, C36: 1uF/25V; C_0603_1608Metric
C28: 4,7uF/25V; C_0603_1608Metric
D1, D2, D3: MBR0530; SOD-123_L2.8-W1.8-LS3.7-RD; MPN MBR0530; LCSC Part C77336
FPC1: AFC01-S24FCA-00; FPC-SMD_24P-P0.50_AFC01-S24FCA-00; MPN AFC01-S24FCA-00; LCSC Part C262669
L1: 1.5uH; IND-SMD_L5.0-W5.0_SWPA5040S; MPN SWPA5040S1R5NT; LCSC Part C96922
L2: 47uH; IND-SMD_L5.8-W5.2
Q1: FS8205A_C908265; SOT-23-6_L2.9-W1.6-P0.95-LS2.8-BR; MPN FS8205A; LCSC Part C908265
Q2: SI1308EDL-T1-GE3; SOT-323_L2.0-W1.3-P1.30-LS2.1-BR; MPN SI1308EDL-T1-GE3; LCSC Part C469327
R1: 6.8k; R_0603_1608Metric
R2: 250; R_0603_1608Metric
R3, R4, R7, R14: 10k; R_0603_1608Metric
R5, R12: 330; R_0603_1608Metric
R6: 10K; R_0603_1608Metric
R8, R9: 4.7k; R_0603_1608Metric
R10: 1M; R_0603_1608Metric
R11: 2,2; R_0603_1608Metric
R13: 1k; R_0402_1005Metric
SW1, SW2: SW_Push; SW-SMD_2P-TS24CA; MPN TS24CA; LCSC Part C393942
U1: CH224K; ESSOP-10_L4.9-W3.9-P1.0-LS6.0-TL-EP; MPN CH224K; LCSC Part C970725
U2: BQ25895RTWR; QFN-24_L4.0-W4.0-P0.50-TL-EP2.7; MPN BQ25895RTWR; LCSC Part C80200
U3: DW01A_C351410; SOT-23-6_L2.9-W1.6-P0.95-LS2.8-BL; MPN DW01A; LCSC Part C351410
U4: BH-21700-B1BJ001; BAT-SMD_L82.5.5-W25-BH-21700-B1BJ001; MPN BH-21700-B1BJ001; LCSC Part C20606791
U5: XC6222A331MR-G; SOT-25-5_L2.9-W1.6-P0.95-LS2.8-BR; MPN XC6222A331MR-G; LCSC Part C5375082
U6: ESP32-C3-WROOM-02-N4; BULETM-SMD_ESPRESSIF_ESP32-C3-WROOM-02-N4-4MB; MPN ESP32-C3-WROOM-02-N4; LCSC Part C2934560
U7: MAX17048G+T10; TDFN-8_L2.0-W2.0-P0.50-BL-EP1.2; MPN MAX17048G+T10; LCSC Part C2682616
U8: SCD40-D-R1; LGA-20_L10.1-W10.1-P1.25-TL; MPN SCD40-D-R1; LCSC Part C3037696
U9: SHT41-AD1B-R2; DFN-4_L1.5-W1.5-SHT41-AD1B-R2; MPN SHT41-AD1B-R2; LCSC Part C7461861
U10: T117Z; TDFN-6_L2.0-W2.0-P0.65-TL-EP; MPN T117Z; LCSC Part C19284876
U11: BH1750FVI-TR; WSOF-6_L2.6-W1.6-P0.50-TL-EP; MPN BH1750FVI-TR; LCSC Part C78960
U12: SGP41-D-R4; DFN-6_L2.4-W2.4-P0.80-TL-EP; MPN SGP41-D-R4; LCSC Part C3659325; not fitted
U13, U14: SK6812MINI-HS; LED-SMD_4P-L3.5-W3.5-BR_SK6812MINI-HS; MPN SK6812MINI-HS; LCSC Part C2922787
U15: USBLC6-2SC6; SOT-23-6
USB1: TYPE-C-2.0-16PIN-SMT-3; TYPE-C-SMD_TYPE-CF3.1; MPN TYPE-C-2.0-16PIN-SMT-3; LCSC Part C2987386

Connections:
+3V3: C12.1, C13.2, C14.2, C15.2, C17.2, C18.1, C19.1, C20.2, C21.2, C22.2, C23.1, C27.2, C29.1, C34.1, C35.1, FPC1.15, FPC1.16, L2.1, R6.2, R7.1, R8.1, R9.1, R14.1, U5.5 (VOUT), U6.1 (3V3), U8.7 (VDD), U8.19 (VDDH), U9.3 (VDD), U10.5 (VDD), U11.1 (VCC), U11.5 (DVI), U12.1 (VDD), U12.5 (VDDH), U13.3 (VDD), U14.3 (VDD)
BAT-: C10.1, Q1.1 (S1), U3.6 (GND), U4.2
CC1: U1.7 (CC1), USB1.A5 (CC1)
CC2: U1.6 (CC2), USB1.B5 (CC2)
CP: C28.2, D2.2 (A), D3.1 (C)
EPD_BUSY: FPC1.9, U6.10 (IO10)
EPD_CS: FPC1.12, U6.15 (IO3)
EPD_DC: FPC1.11, U6.5 (IO6)
EPD_RES: FPC1.10, U6.6 (IO7)
EPD_SCLK: FPC1.13, U6.18 (IO0)
EPD_SDI: FPC1.14, U6.17 (IO1)
ESD_D+: U6.14 (IO19), U15.4 (I/O2)
ESD_D-: U6.13 (IO18), U15.6 (I/O1)
GDR: FPC1.2, Q2.1 (G), R10.1
GND: C1.2, C2.2, C3.2, C4.2, C6.1, C7.1, C8.1, C9.1, C11.1, C12.2, C13.1, C14.1, C15.1, C16.1, C17.1, C18.2, C19.2, C20.1, C21.1, C22.1, C23.2, C24.2, C25.2, C26.1, C27.1, C29.2, C30.1, C31.2, C32.1, C33.2, C34.2, C35.2, C36.2, D2.1 (C), FPC1.8, FPC1.17, FPC1.25, FPC1.26, Q1.3 (S2), R1.2, R2.2, R4.2, R10.2, R11.2, R13.1, SW1.2, SW2.2, U1.11 (GND), U2.8 (OTG), U2.9 (CE), U2.17 (PGND), U2.18 (PGND), U2.25 (PAD), U5.2 (VSS), U6.9 (GND), U6.19 (EP), U7.1 (CTG), U7.4 (GND), U7.6 (QSTRT), U7.9 (EP), U8.6 (GND), U8.20 (GND), U8.21 (GND), U9.4 (VSS), U10.2 (GND), U10.4 (ADDR), U10.7 (EP), U11.2 (ADDR), U11.3 (GND), U11.7 (EP), U12.2 (VSS), U12.4 (n/a), U12.7 (EP), U13.1 (GND), U14.1 (GND), U15.2 (GND), USB1.1 (EH), USB1.A1 (GND), USB1.A12 (GND), USB1.B1 (GND), USB1.B12 (GND)
unnamed: C5.1, L1.1, U2.19 (SW), U2.20 (SW)
unnamed: C25.1, FPC1.18
unnamed: C26.2, FPC1.19
unnamed: Q1.6 (G1), U3.1 (OD)
unnamed: Q1.4 (G2), U3.3 (OC)
unnamed: R1.1, U1.9 (CFG1)
unnamed: C2.1, U1.1 (VDD)
unnamed: C5.2, U2.21 (BTST)
unnamed: R2.1, U2.10 (ILIM)
unnamed: C4.1, U2.23 (PMID)
unnamed: R3.2, R4.1, U2.11 (TS)
unnamed: C10.2, R5.1, U3.5 (VCC)
unnamed: R13.2, U3.2 (VM)
unnamed: R6.1, SW2.1, U6.2 (EN)
unnamed: R12.1, R14.2, U6.16 (IO2)
unnamed: R7.2, U6.7 (IO8)
unnamed: SW1.1, U6.8 (IO9)
unnamed: R12.2, U13.2 (DIN)
unnamed: U13.4 (DOUT), U14.2 (DIN)
REGN: C6.2, R3.1, U2.22 (REGN)
RESE: FPC1.3, Q2.2 (S), R11.1
SCL: R9.2, U2.5 (SCL), U6.4 (IO5), U7.7 (SCL), U8.9 (SCL), U9.2 (SCL), U10.1 (SCL), U11.6 (SCL), U12.6 (SCL)
SDA: R8.2, U2.6 (SDA), U6.3 (IO4), U7.8 (SDA), U8.10 (SDA), U9.1 (SDA), U10.6 (SDA), U11.4 (SDA), U12.3 (SDA)
SW: C28.1, D1.2 (A), L2.2, Q2.3 (D)
SYS: C7.2, C8.2, C11.2, L1.2, U2.15 (SYS), U2.16 (SYS), U5.1 (VIN), U5.3 (CE)
USB_D+: U15.3 (I/O2), USB1.A6 (DP1), USB1.B6 (DP2)
USB_D-: U15.1 (I/O1), USB1.A7 (DN1), USB1.B7 (DN2)
VBAT: C9.2, C16.2, R5.2, U2.13 (BAT), U2.14 (BAT), U4.1, U7.2 (CELL), U7.3 (VDD)
VBUS: C1.1, C3.1, U1.8 (VBUS), U2.1 (VBUS), U15.5 (VBUS), USB1.A4 (VBUS), USB1.A9 (VBUS), USB1.B4 (VBUS), USB1.B9 (VBUS)
VCOM: C31.1, FPC1.24
VGH: C24.1, D1.1 (C), FPC1.21
VGL: C36.1, D3.2 (A), FPC1.23
VSH1: C30.2, FPC1.20
VSH2: C32.2, FPC1.5
VSL: C33.1, FPC1.22

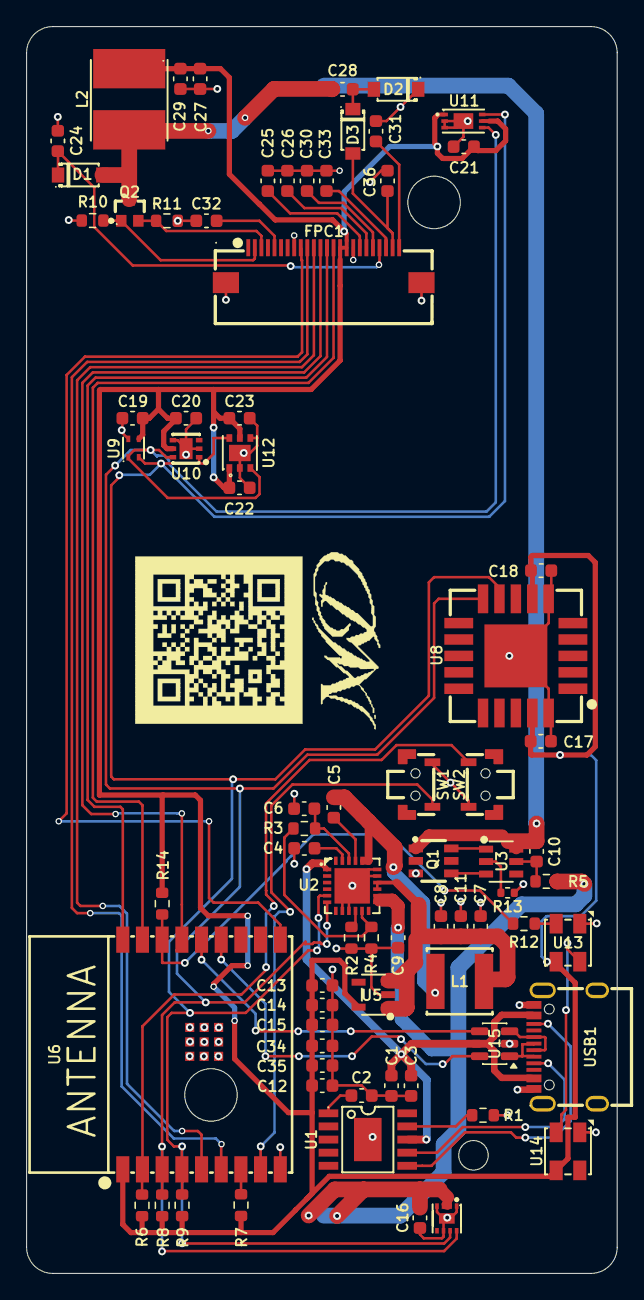
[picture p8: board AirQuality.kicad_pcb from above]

Board: 2 copper layers, 45.0 x 95.0 mm, 78 parts (1 on the bottom side), 50 nets.

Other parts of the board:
LOGO: MWD_Logo
QR: https://github.com/MorgenWebDigital; MWD_QR_GitHub

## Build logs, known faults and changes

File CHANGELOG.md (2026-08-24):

# Changelog

This file follows [Keep a Changelog](https://keepachangelog.com/en/1.1.0/), and
the versions follow [semantic versioning](https://semver.org/).

## [Unreleased]

### Fixed

- the 3.3 v regulator was held off. its ce pin is active high and sat on
  ground, so the whole board had no supply. ce now goes to sys
- all three schottky diodes of the display supply were reversed. the mbr0530
  symbol has the cathode on pin 1, and the boost needs its anode at the
  switching node. as drawn, vgh could never charge and the mosfet saw
  unclamped flyback
- vgl had no bulk capacitor. the reference circuit calls for 1 µf; the other
  twelve were present, that one was missing
- the dw01a's vm pin sat directly on ground. its datasheet puts 1 kΩ in series,
  because vm sees the full charger voltage when the protection has tripped

### Added

- esd protection on the usb data lines, routed through the device and 1.9 mm
  from the connector, with a ground via at its ground pad
- pull-up on io2. espressif recommends it against glitches on that strapping
  pin
- pin 4 of the sgp41 tied to ground, as its datasheet asks
- voltage rating on the seven display rail capacitors. vgh runs above 20 v and
  a stock 1 µf 0603 is often a 16 v part

### Changed

- qr code on the silkscreen now points at the github account instead of the
  shop. same size, verified by decoding it back out of the footprint file
- track widths on the power nets follow ipc-2221 at a 10 k rise
